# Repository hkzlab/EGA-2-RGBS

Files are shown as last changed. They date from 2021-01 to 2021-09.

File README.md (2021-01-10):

# EGA-2-RGBS

Months ago I ran into [this](https://www.youtube.com/watch?v=vwKA1z8tg1g&t=527) video on YouTube that described how to implement an EGA/CGA to analog RGBS signal using just a ROM and a few passive components.
Thinking it was a nice idea, I decided to implement my variant of it (including the tool that generates the values to program the EPROM), also including an optional buffer on the outputs of the ROM.

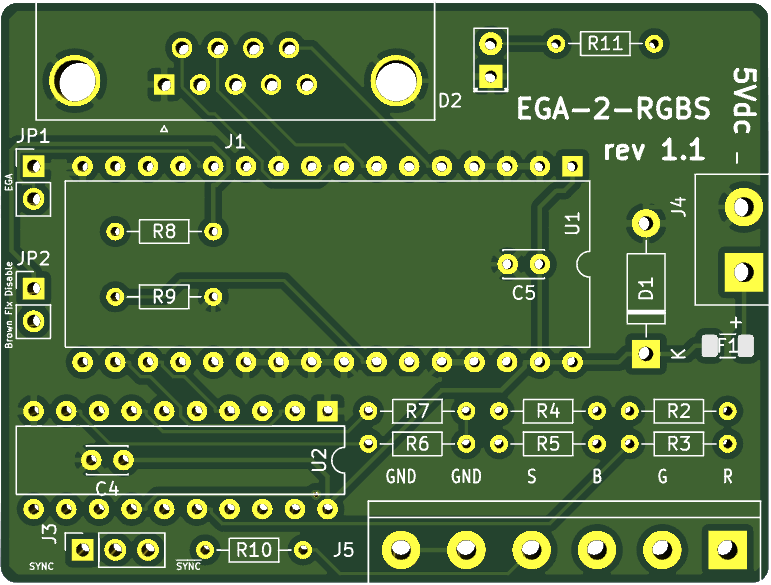
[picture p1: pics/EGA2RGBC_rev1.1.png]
Rev. 1.1 PCB


**CAVEAT EMPTOR:** For now I tested this board only in DOS with a CGA card. Will update this note when I test EGA and colours.

Note that this **will not convert EGA/CGA to VGA**, it will just make the signal analog and compatible with either a SCART input or a scaler like the GBS8200 (tested with [gbs-control](https://github.com/ramapcsx2/gbs-control) firmware).

## Jumpers

- JP1: Bridge if you are using this with an EGA card, remove bridge for CGA
- JP2: Disable Brown colour fix for CGA. No effect on EGA
- JP3: Bridge 1-2 to output a CSYNC signal, bridge 2-3 for /CSYNC

## Building the board

### BOM

- 1x 20pin socket (on U2)
- 1x 32pin wide socket (on U1)
- 2x 100nF ceramic caps (C5 and C4)
- 1x Right angle DB9 female PCB connector (J1)
- 1x 6 or 5 pin screw terminal (J5)
- 1x 2 pin screw terminal (J4)
- 1x 1206 SMD fuse rated around ~100mA (F1), **100mA is already very high for the power consumption of the board, but I had these at hand** 
- 1x 3 pin 2.54mm male pcb header, plus jumper (J3)
- 2x 2 pin 2.54mm male pcb header, plus jumpers (JP1 and JP2)
- 1x First random led you have at hand, optional (D2)
- 1x 1N4733A 5.1v zener diode (D1)
- 1x 74HC244 DIP, optional (U2)
- 1x 27C010 DIP (U1)
- 4x 470 1/4w resistors (R2, R4, R6, R10)
- 3x 1.5k 1/4w resistors (R3, R5, R7)
- 1x 1k 1/4w resistor (R11)
- 2x 4.7k 1/4w resistors (R8, R9)

Remember to program the EPROM with the bin file provided in the repository.

### Building on the cheap

You can omit the following components:

#### Power

Omit F1 and D1, bridge the two connections points of F1. Do this if you trust your power supply and yourself not to make shorts.

You can also omit the power indicator led D2 and its resistor R11

#### Sockets

You can omit both U1 and U2 sockets. Remember to mount C4, C5, R8 and R9 on the underside of the board if you do this.

#### Output buffer

You can omit U2 entirely. Just bridge the following points on the footprint:

- 2->18
- 4->16
- 6->14
- 8->12
- 11->9
- 13->7
- 15->5
- 17->3

Also omit C4 in this case.

## Credits

- [TheRasteri](https://www.youtube.com/channel/UCO1ifHwXHkEyCLFk2b7Z8xA) on YouTube for the original idea

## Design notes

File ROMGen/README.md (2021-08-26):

# ROM/PLD generator for EGA-2-RGBS board

This tool generates a ROM image or a truth table (that can be then simplified with espresso) that can be used on the EGA-2-RGBS board.

TODO: Write some more documentation

## Example

Table generated for a PLD:

```text
obh = (bh);

obl = (!mode&bl) | (mode&gli);

ogh = (gh&bfix) | (gh&!rh) | (bh&gh) | (gh&gli) | (!mode&gh);

ogl = (mode&!bh&gh&rh&!bfix) | (gli);

orh = (rh);

orl = (!mode&rl) | (mode&gli);

ocs = (vs&!hs) | (!vs&hs);

oncs = (!vs&!hs) | (vs&hs);
```

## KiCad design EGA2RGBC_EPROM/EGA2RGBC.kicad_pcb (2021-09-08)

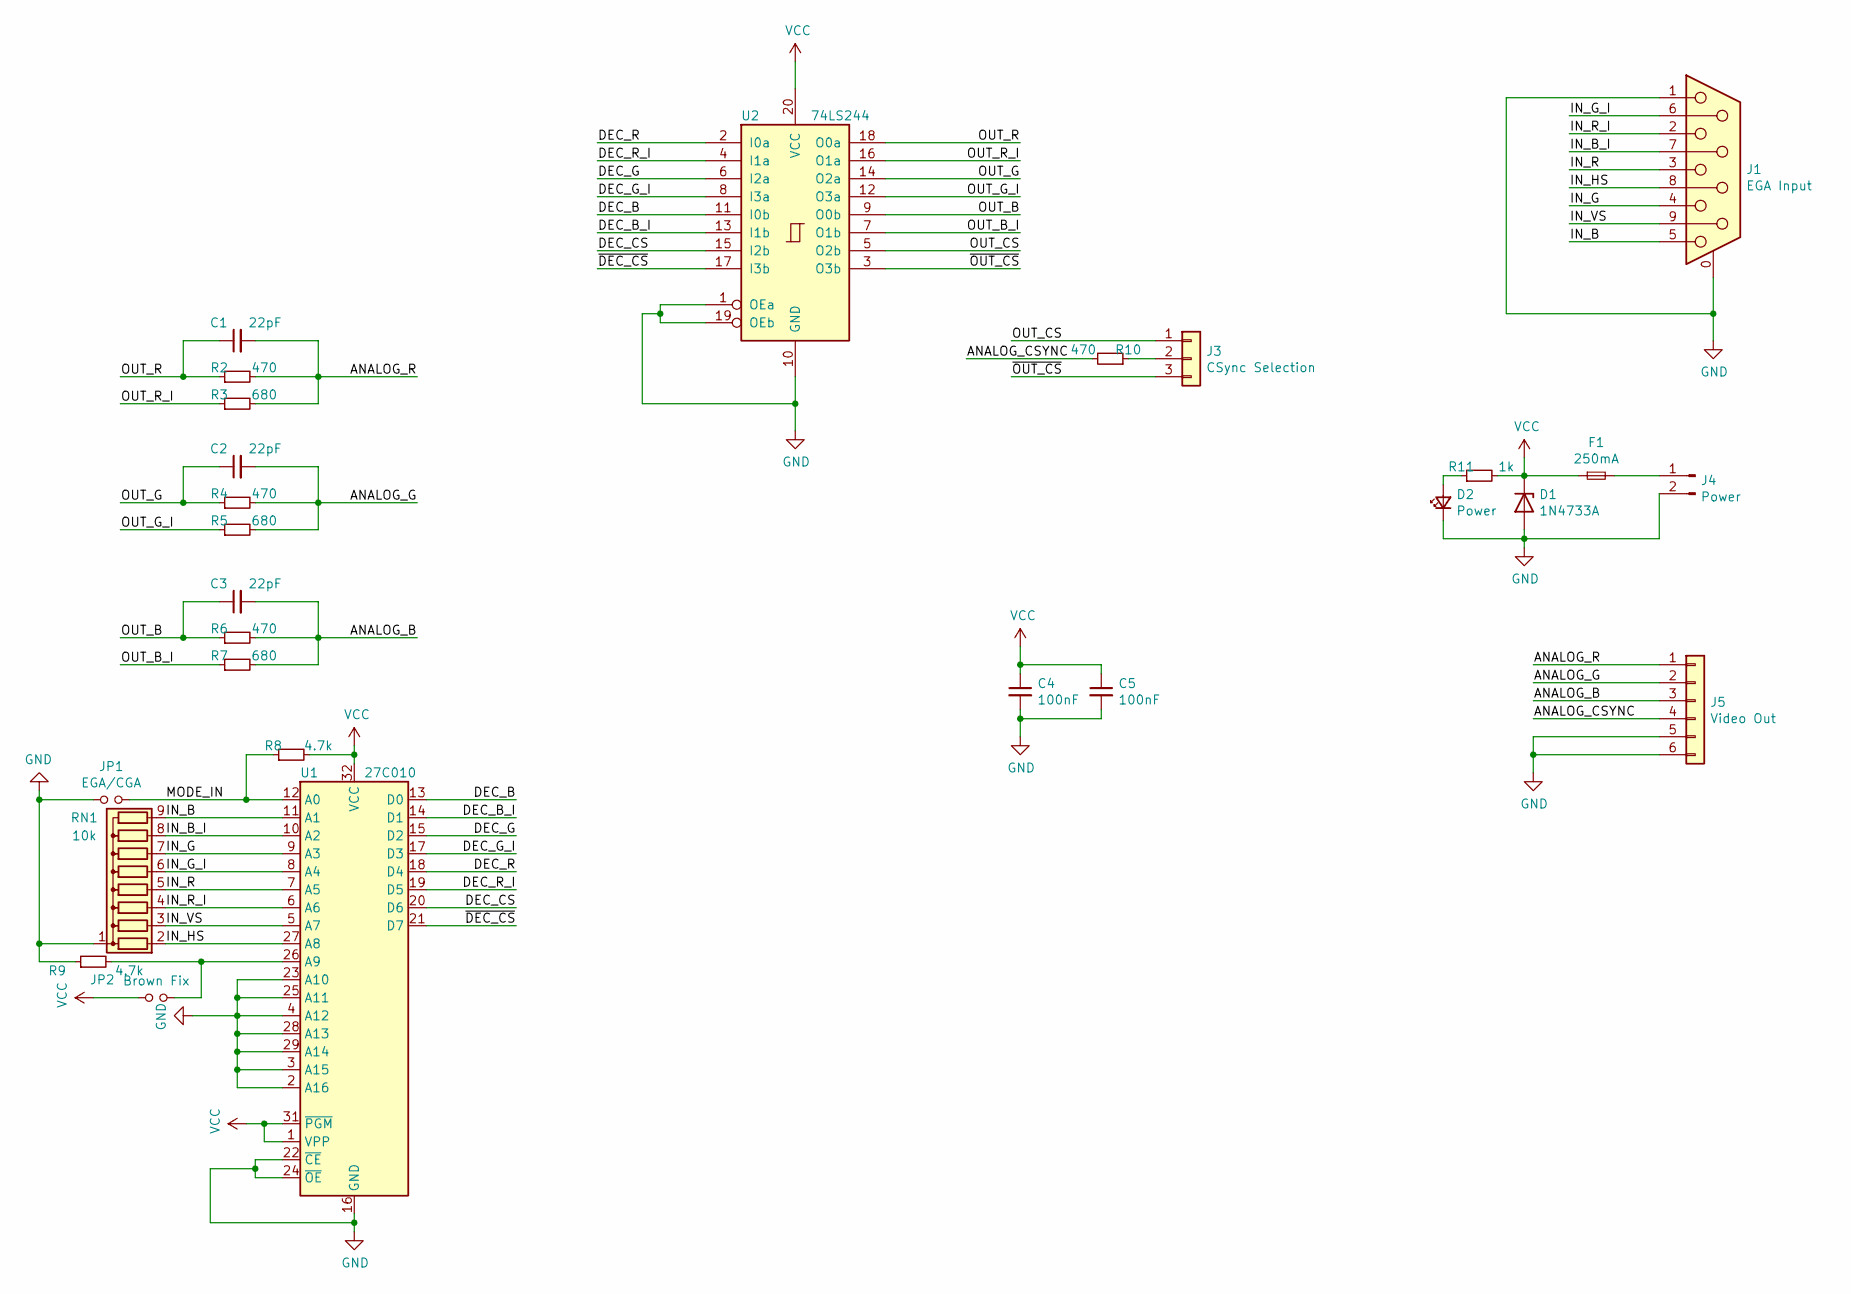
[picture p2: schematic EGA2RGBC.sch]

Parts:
C1, C2, C3: 22pF; C_Disc_D3.0mm_W2.0mm_P2.50mm
C4, C5: 100nF; C_Disc_D3.0mm_W2.0mm_P2.50mm
D1: 1N4733A; D_DO-41_SOD81_P10.16mm_Horizontal
D2: Power; LED_D2.0mm_W4.8mm_H2.5mm_FlatTop
F1: 250mA; Fuse_1206_3216Metric
J1: EGA Input; DSUB-9_Female_Horizontal_P2.77x2.84mm_EdgePinOffset4.94mm_H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
J3: CSync Selection; PinSocket_1x03_P2.54mm_Vertical
J4: Power; TerminalBlock_bornier-2_P5.08mm
J5: Video Out; TerminalBlock_bornier-6_P5.08mm
JP1: EGA/CGA; PinHeader_1x02_P2.54mm_Vertical
JP2: Brown Fix; PinHeader_1x02_P2.54mm_Vertical
R2, R4, R6, R10: 470; R_Axial_DIN0204_L3.6mm_D1.6mm_P7.62mm_Horizontal
R3, R5, R7: 680; R_Axial_DIN0204_L3.6mm_D1.6mm_P7.62mm_Horizontal
R8, R9: 4.7k; R_Axial_DIN0204_L3.6mm_D1.6mm_P7.62mm_Horizontal
R11: 1k; R_Axial_DIN0204_L3.6mm_D1.6mm_P7.62mm_Horizontal
RN1: 10k; R_Array_SIP9
U1: 27C010; DIP-32_W15.24mm
U2: 74LS244; DIP-20_W7.62mm

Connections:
/ANALOG_B: C3.2, J5.3, R6.2, R7.2
/ANALOG_CSYNC: J5.4, R10.2
/ANALOG_G: C2.2, J5.2, R4.2, R5.2
/ANALOG_R: C1.2, J5.1, R2.2, R3.2
/DEC_B: U1.13 (D0), U2.11 (I0b)
/DEC_B_I: U1.14 (D1), U2.13 (I1b)
/DEC_CS: U1.20 (D6), U2.15 (I2b)
/DEC_G: U1.15 (D2), U2.6 (I2a)
/DEC_G_I: U1.17 (D3), U2.8 (I3a)
/DEC_R: U1.18 (D4), U2.2 (I0a)
/DEC_R_I: U1.19 (D5), U2.4 (I1a)
/IN_B: J1.5, RN1.9 (R8), U1.11 (A1)
/IN_B_I: J1.7, RN1.8 (R7), U1.10 (A2)
/IN_G: J1.4, RN1.7 (R6), U1.9 (A3)
/IN_G_I: J1.6, RN1.6 (R5), U1.8 (A4)
/IN_HS: J1.8, RN1.2 (R1), U1.27 (A8)
/IN_R: J1.3, RN1.5 (R4), U1.7 (A5)
/IN_R_I: J1.2, RN1.4 (R3), U1.6 (A6)
/IN_VS: J1.9, RN1.3 (R2), U1.5 (A7)
/MODE_IN: JP1.2, R8.1, U1.12 (A0)
/OUT_B: C3.1, R6.1, U2.9 (O0b)
/OUT_B_I: R7.1, U2.7 (O1b)
/OUT_CS: J3.1, U2.5 (O2b)
/OUT_G: C2.1, R4.1, U2.14 (O2a)
/OUT_G_I: R5.1, U2.12 (O3a)
/OUT_R: C1.1, R2.1, U2.18 (O0a)
/OUT_R_I: R3.1, U2.16 (O1a)
/~DEC_CS: U1.21 (D7), U2.17 (I3b)
/~OUT_CS: J3.3, U2.3 (O3b)
GND: C4.2, C5.2, D1.2 (A), D2.1 (K), J1.0 (PAD), J1.1, J4.2, J5.5, J5.6, JP1.1, R9.1, RN1.1 (common), U1.2 (A16), U1.3 (A15), U1.4 (A12), U1.16 (GND), U1.22 (~CE), U1.23 (A10), U1.24 (~OE), U1.25 (A11), U1.28 (A13), U1.29 (A14), U2.1 (OEa), U2.10 (GND), U2.19 (OEb)
unnamed: D2.2 (A), R11.1
unnamed: F1.2, J4.1
unnamed: J3.2, R10.1
unnamed: JP2.2, R9.2, U1.26 (A9)
VCC: C4.1, C5.1, D1.1 (K), F1.1, JP2.1, R8.2, R11.2, U1.1 (VPP), U1.31 (~PGM), U1.32 (VCC), U2.20 (VCC)

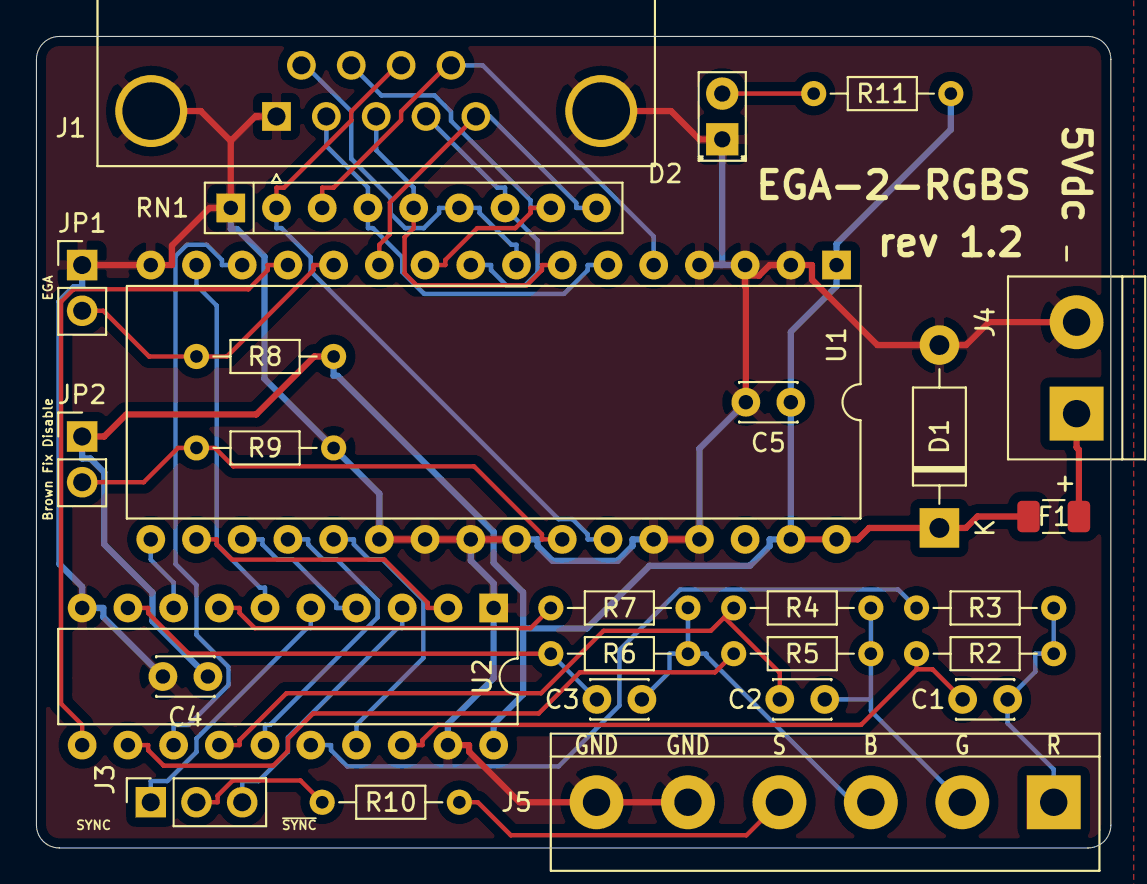
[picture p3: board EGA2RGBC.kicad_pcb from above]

Board: 2 copper layers, 59.7 x 45.1 mm, 27 parts (0 on the bottom side), 35 nets.

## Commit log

2020-11-26 Schematics for EGA to RGB
    [EGA2RGBC.kicad_pcb, EGA2RGBC.sch]
2020-11-26 Added footprints
    [EGA2RGBC.kicad_pcb, EGA2RGBC.sch]
2020-11-26 Fix labels and generate gerbers
    [EGA2RGBC.kicad_pcb, EGA2RGBC.sch]
2020-11-26 Update PCB
    [EGA2RGBC.kicad_pcb]
2020-11-26 Add EGA2RGBC eprom version
    [EGA2RGBC.kicad_pcb, EGA2RGBC.sch]
2020-11-27 Update schematics
    [EGA2RGBC.kicad_pcb, EGA2RGBC.sch]
2020-11-27 Moved resistors
    [EGA2RGBC.kicad_pcb]
2021-01-10 Create rev 1.1
    [EGA2RGBC.kicad_pcb, EGA2RGBC.sch]
2021-01-10 Removed EPROMless version
    [EGA2RGBC.kicad_pcb, EGA2RGBC.sch]
2021-01-10 Add rev 1.1 files
    [EGA2RGBC.kicad_pcb]
2021-08-16 Added caps on color lines
    [EGA2RGBC.sch]
2021-09-07 Change some resistor values
    [EGA2RGBC.sch]
2021-09-08 Add pulldown resistor to inputs
    [EGA2RGBC.sch]
2021-09-08 Add new revision of board
    [EGA2RGBC.kicad_pcb, EGA2RGBC.sch]
2021-11-09 Update KiCad URL
